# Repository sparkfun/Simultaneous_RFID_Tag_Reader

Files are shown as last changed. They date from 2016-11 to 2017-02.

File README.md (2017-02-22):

SparkFun Simultaneous RFID Tag Reader Breakout
=============================================

SparkFun Simultaneous RFID Tag Reader

[* SparkFun Simultaneous RFID Tag Reader Breakout](https://www.sparkfun.com/products/14066)

A breakout board the for UHF RFID module (M6E-NANO) from ThingMagic. 
Capable of reading multiple 860-920MHz UHF RFID tags at the same time with increased read distance. 
You can also write to tags to boot. 

Board works either as shield or as stand alone device (using a USB to Serial converter).

Repository Contents
-------------------

* **/Documentation** - Data sheets, additional product information
* **/Hardware** - Eagle design files (.brd, .sch)
* **/Libraries** - Libraries for use with the Simultaneous RFID Tag Reader
* **/Production** - Production panel files (.brd)

Documentation
--------------
* **[Library](https://github.com/sparkfun/SparkFun_Simultaneous_RFID_Tag_Reader_Library)** - Arduino library for the Tag Reader.
* **[Hookup Guide](https://learn.sparkfun.com/tutorials/simultaneous-rfid-tag-reader-hookup-guide)** - Basic hookup guide for the Tag Reader.
* **[SparkFun Fritzing repo](https://github.com/sparkfun/Fritzing_Parts)** - Fritzing diagrams for SparkFun products.
* **[SparkFun 3D Model repo](https://github.com/sparkfun/3D_Models)** - 3D models of SparkFun products. 

License Information
-------------------

This product is _**open source**_! 

Please review the LICENSE.md file for license information. 

If you have any questions or concerns on licensing, please contact techsupport@sparkfun.com.

Distributed as-is; no warranty is given.

- Your friends at SparkFun.

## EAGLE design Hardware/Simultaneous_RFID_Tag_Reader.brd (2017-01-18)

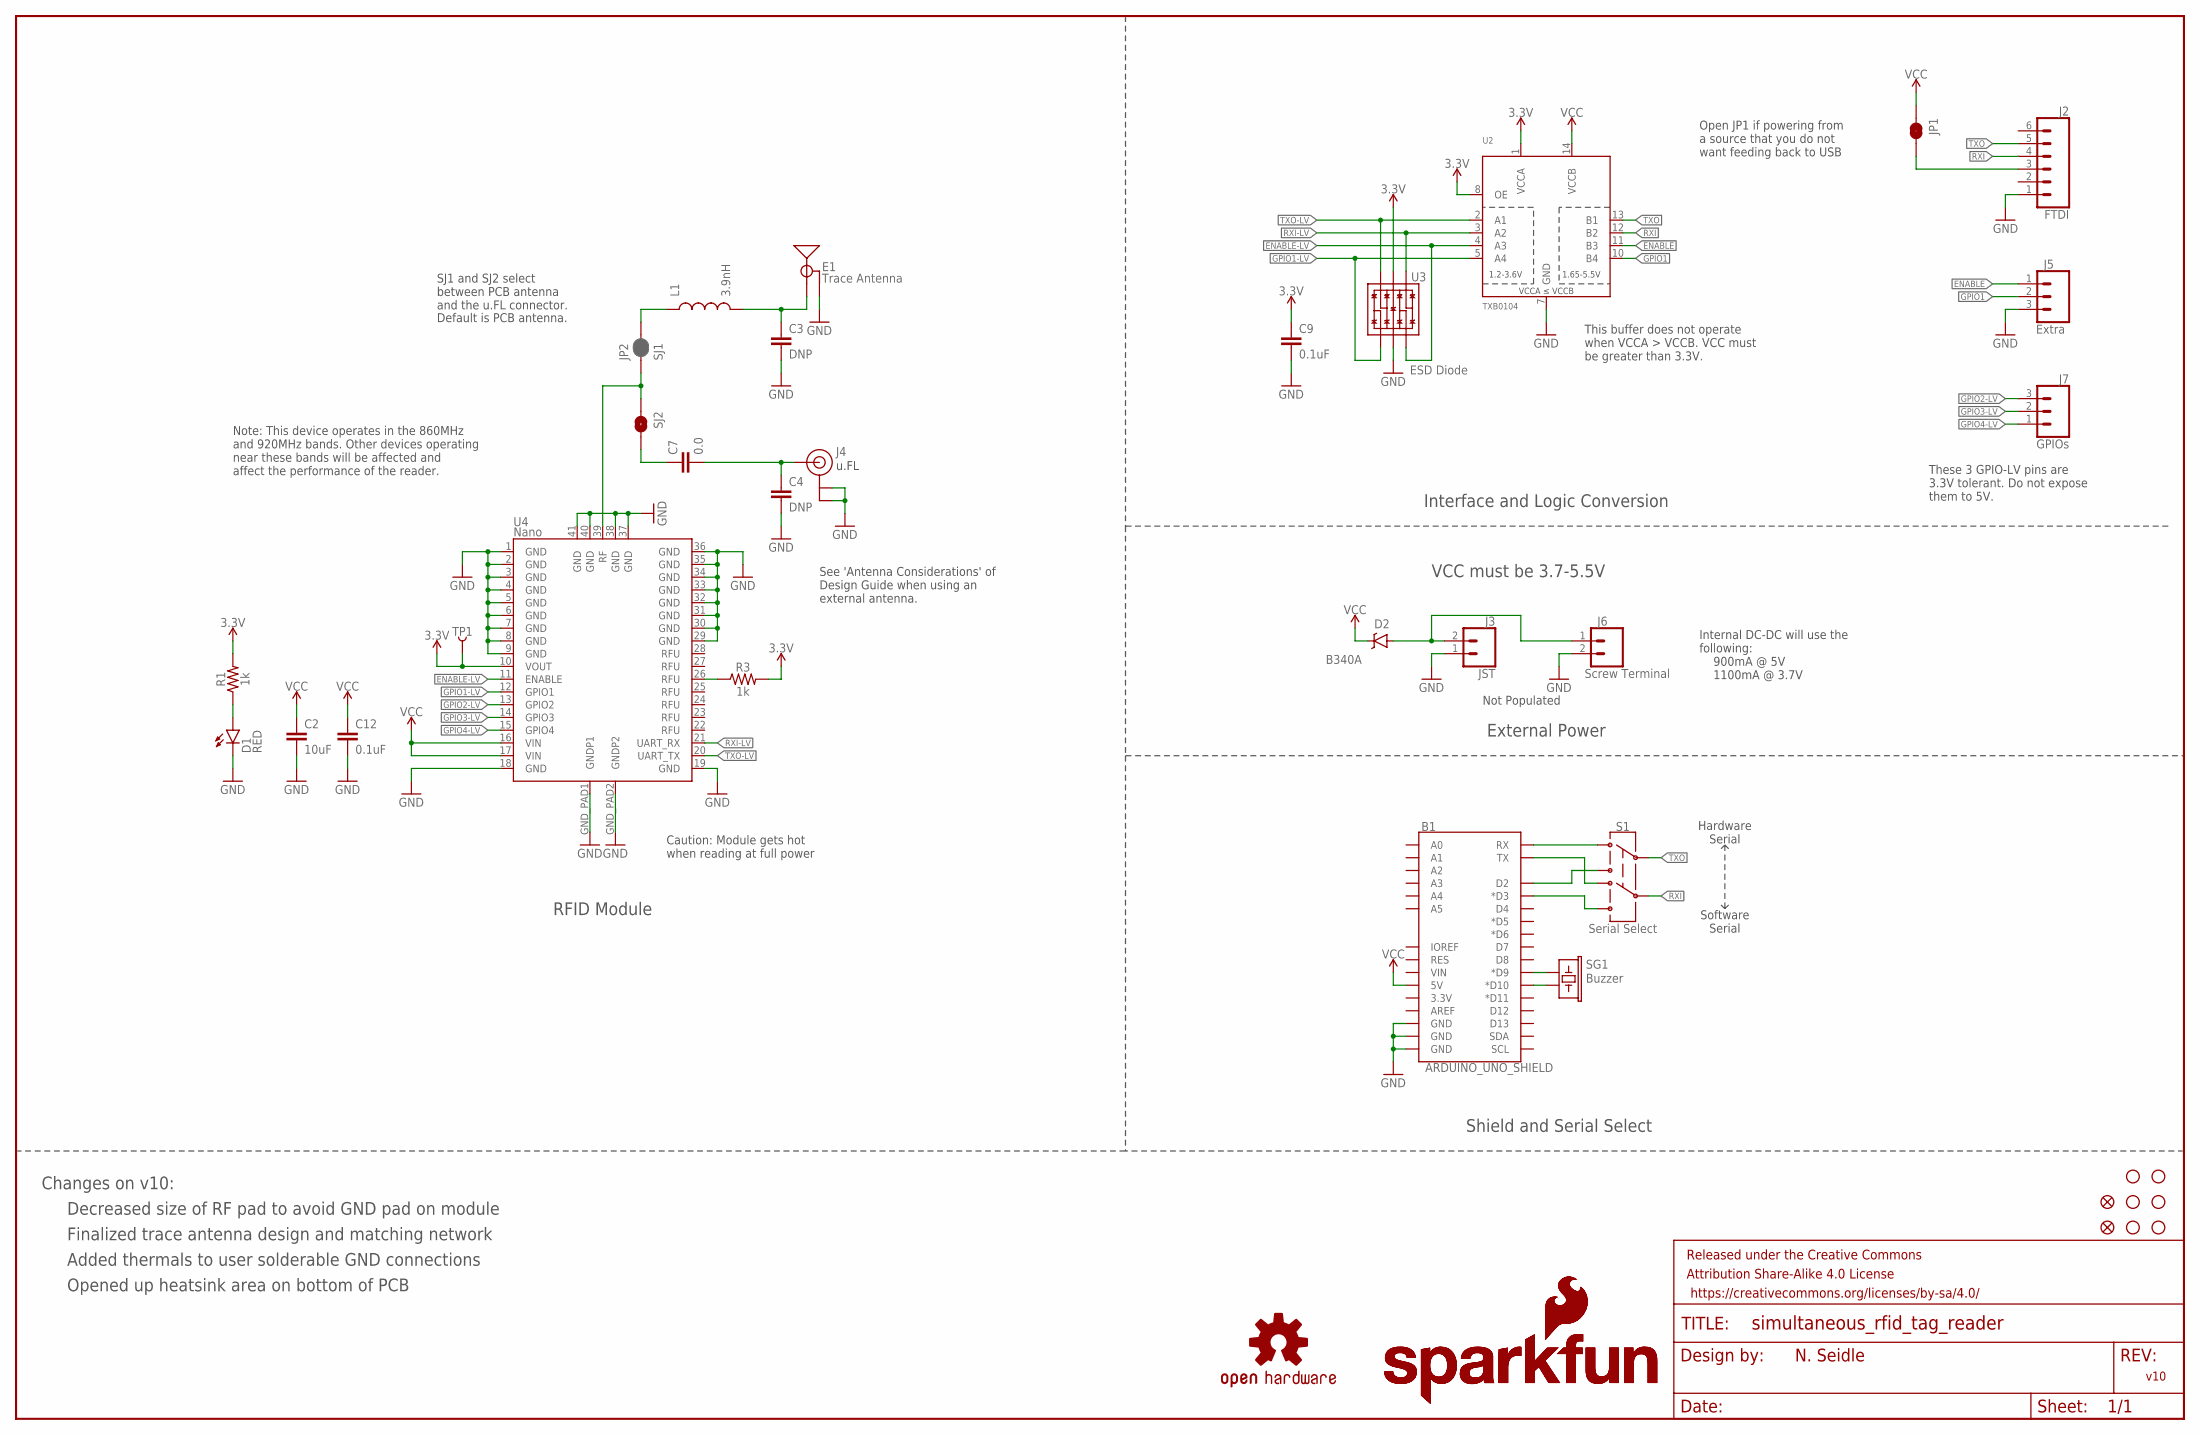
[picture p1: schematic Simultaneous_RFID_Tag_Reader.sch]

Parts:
B1: ARDUINO_UNO_SHIELD; UNO_R3_SHIELD
C2: 10uF; 0805
C3, C4: DNP; 0603
C7: 0.0; 0603
C9, C12: 0.1uF; 0603
D1: RED; LED-0603
D2: B340A; SMA-DIODE
E1: Trace Antenna; 915MHZ_ANTENNA_TRIMBLE
FID1, FID2: FIDUCIAL1X2; FIDUCIAL-1X2
FRAME1: FRAME-LEDGER; CREATIVE_COMMONS
J2: FTDI; 1X06
J3: JST; JST-2-PTH
J4: U.FL
J5: Extra; 1X03
J6: Screw Terminal; SCREWTERMINAL-3.5MM-2
J7: GPIOs; 1X03
JP1: JUMPER-SMT_2_NC_TRACE_SILK; SMT-JUMPER_2_NC_TRACE_SILK
JP2: SJ1; SMT-JUMPER_2_NO_NO-SILK
L1: 3.9nH; 0603
LOGO1, LOGO3: SFE_LOGO_NAME_FLAME.1_INCH; SFE_LOGO_NAME_FLAME_.1
LOGO2: OSHW-LOGOS; OSHW-LOGO-S
R1, R3: 1k; 0603
S1: Serial Select; SWITCH_DPDT_SMD_AYZ0202
SG1: Buzzer; BUZZER-CCV
SJ2: JUMPER-SMT_2_NO_NO-SILK; SMT-JUMPER_2_NO_NO-SILK
STANDOFF1, STANDOFF2, STANDOFF3, STANDOFF4, STANDOFF7, STANDOFF8: STAND-OFF
TP1: TEST-POINT3; PAD.03X.03
U2: TXB0104; SO14
U3: ESD Diode; SOT-23-6
U4: Nano; NANO_MODULE

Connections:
3.3V: C9.1, R1.2, R3.2, TP1.P$1, U2.1 (VCCA), U2.8 (OE), U3.5 (VCC), U4.10 (VOUT)
ANT3: JP2.1, SJ2.1, U4.39 (RF)
ENABLE: J5.1, U2.11 (B3)
ENABLE-LV: U2.4 (A3), U3.3 (IO2), U4.11 (ENABLE)
GND: B1.GND@0 (GND), B1.GND@1 (GND), B1.GND@2 (GND), C2.2, C3.2, C4.2, C9.2, C12.2, D1.C, E1.GND@1 (GND), E1.GND@2 (GND), E1.GND@3 (GND), J2.1, J3.1, J4.P$1 (GND), J4.P$2 (GND), J5.3, J6.2, U2.7 (GND), U3.2 (VSS), U4.1 (GND), U4.2 (GND), U4.3 (GND), U4.4 (GND), U4.5 (GND), U4.6 (GND), U4.7 (GND), U4.8 (GND), U4.9 (GND), U4.18 (GND), U4.19 (GND), U4.29 (GND), U4.30 (GND), U4.31 (GND), U4.32 (GND), U4.33 (GND), U4.34 (GND), U4.35 (GND), U4.36 (GND), U4.37 (GND), U4.38 (GND), U4.40 (GND), U4.41 (GND), U4.GND_PAD1 (GNDP1), U4.GND_PAD2 (GNDP2)
GPIO1: J5.2, U2.10 (B4)
GPIO1-LV: U2.5 (A4), U3.1 (IO1), U4.12 (GPIO1)
GPIO2-LV: J7.3, U4.13 (GPIO2)
GPIO3-LV: J7.2, U4.14 (GPIO3)
GPIO4-LV: J7.1, U4.15 (GPIO4)
unnamed: C3.1, E1.ANT (SIGNAL), L1.2
unnamed: JP2.2, L1.1
unnamed: C7.1, SJ2.2
unnamed: R3.1, U4.26 (RFU)
unnamed: C4.1, C7.2, J4.P$3 (SIGNAL)
unnamed: D1.A, R1.1
unnamed: J2.3, JP1.2
unnamed: B1.RX, S1.1
unnamed: B1.TX, S1.4
unnamed: B1.D9 (*D9), SG1.+ (1)
unnamed: D2.A, J3.2, J6.1
unnamed: B1.D10 (*D10), SG1.- (2)
RXI: J2.4, S1.5, U2.12 (B2)
RXI-LV: U2.3 (A2), U3.4 (IO3), U4.21 (UART_RX)
SOFT-RX: B1.D2, S1.3
SOFT-TX: B1.D3 (*D3), S1.6
TXO: J2.5, S1.2, U2.13 (B1)
TXO-LV: U2.2 (A1), U3.6 (IO4), U4.20 (UART_TX)
VCC: B1.5V, C2.1, C12.1, D2.C, JP1.1, U2.14 (VCCB), U4.16 (VIN), U4.17 (VIN)

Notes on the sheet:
v10
N. Seidle
Interface and Logic Conversion
VCC must be 3.7-5.5V
Internal DC-DC will use the following: 900mA @ 5V 1100mA @ 3.7V
RFID Module
SJ1 and SJ2 select between PCB antenna and the u.FL connector.
Note: This device operates in the 860MHz and 920MHz bands. Other devices operating near these bands will be affected and affect the performance of the reader.
See 'Antenna Considerations' of Design Guide when using an external antenna.
u.FL
Hardware Serial
Software Serial
External Power
Shield and Serial Select
Default is PCB antenna.
Not Populated
Open JP1 if powering from a source that you do not want feeding back to USB
These 3 GPIO-LV pins are 3.3V tolerant. Do not expose them to 5V.
Decreased size of RF pad to avoid GND pad on module
Finalized trace antenna design and matching network
Changes on v10:
Added thermals to user solderable GND connections
Caution: Module gets hot when reading at full power
Opened up heatsink area on bottom of PCB
This buffer does not operate when VCCA > VCCB. VCC must be greater than 3.3V.

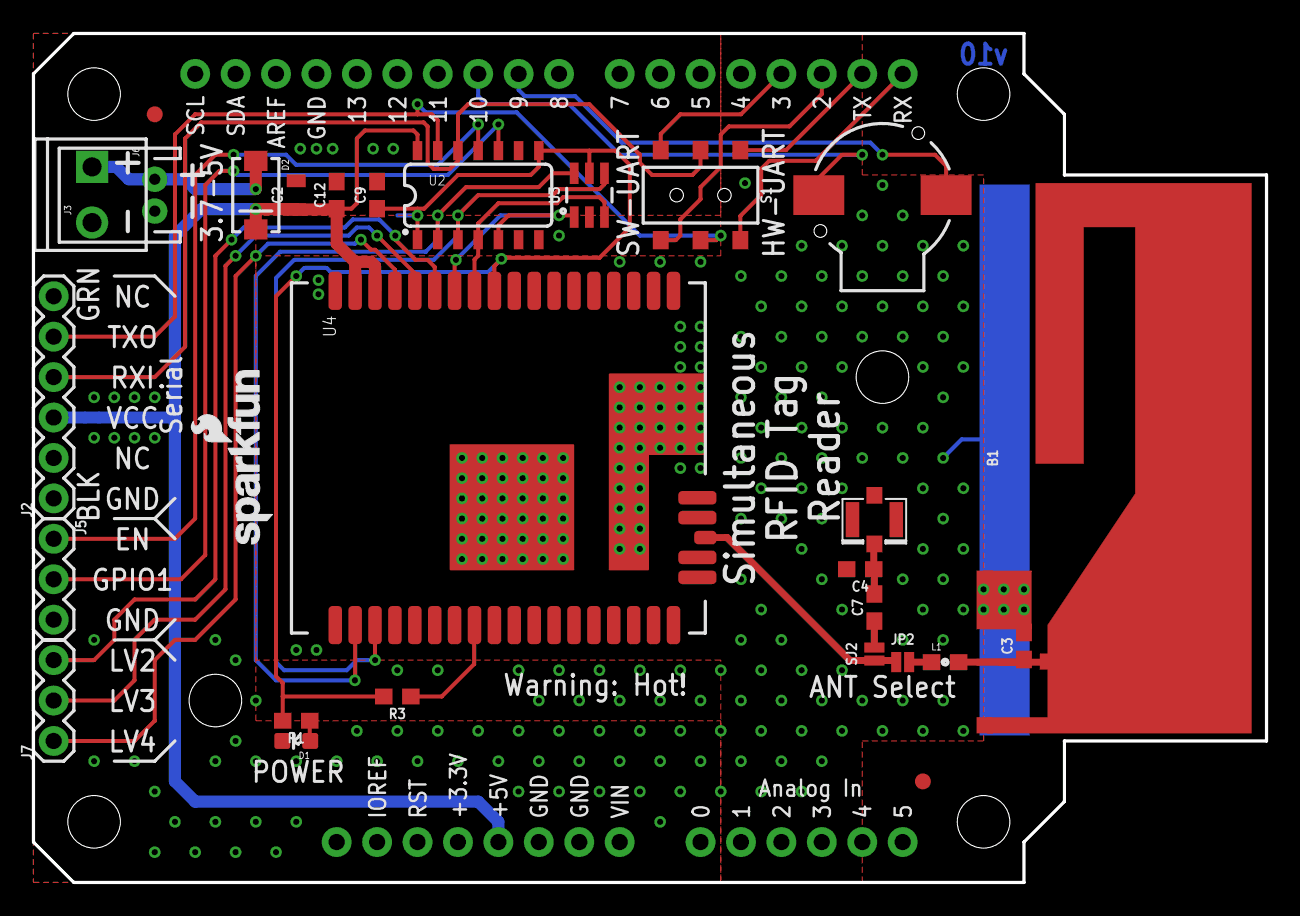
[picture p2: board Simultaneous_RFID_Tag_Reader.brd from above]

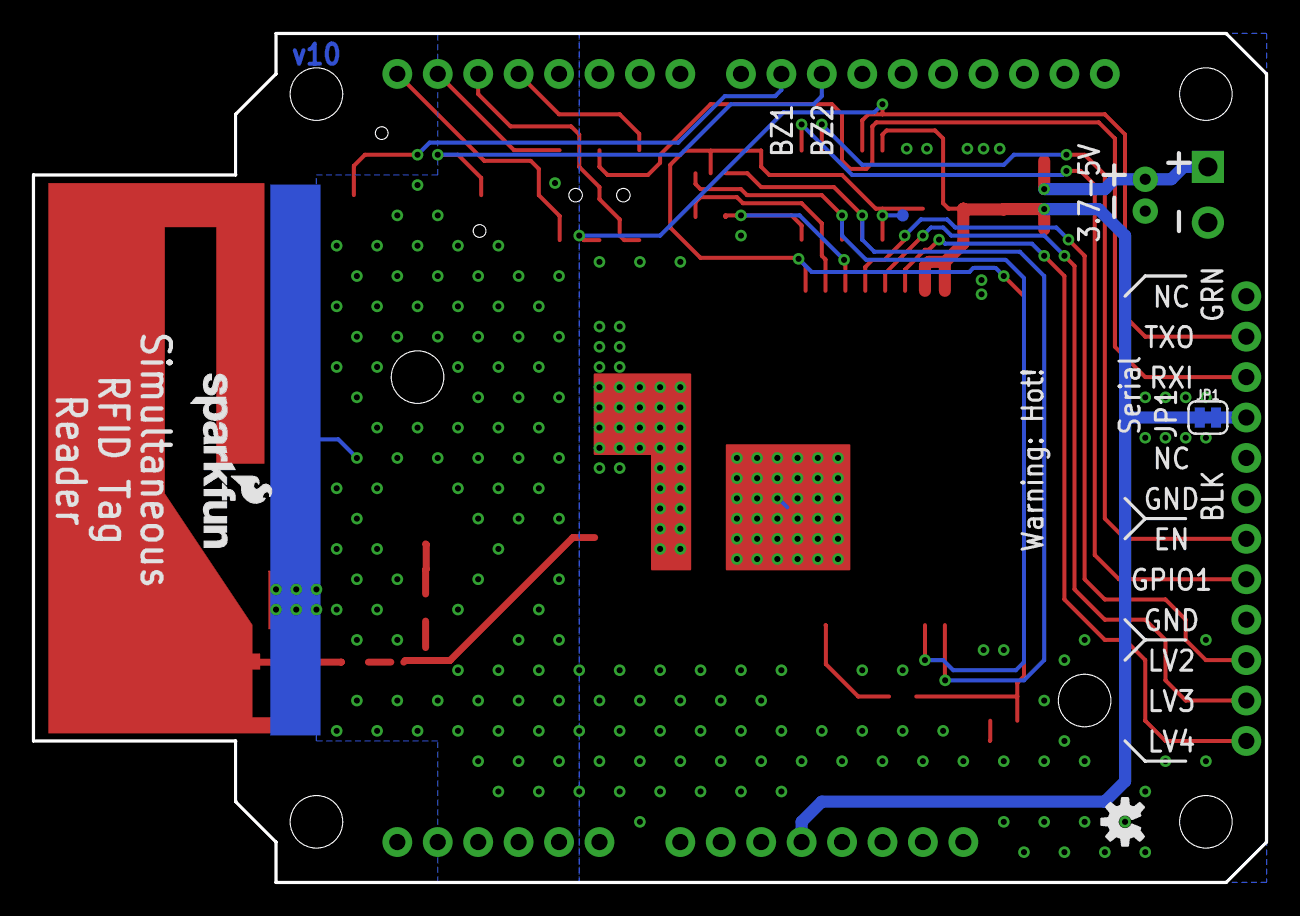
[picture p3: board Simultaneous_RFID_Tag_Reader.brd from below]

Board: 2 copper layers, 77.5 x 53.3 mm, 40 parts (4 on the bottom side), 29 nets.

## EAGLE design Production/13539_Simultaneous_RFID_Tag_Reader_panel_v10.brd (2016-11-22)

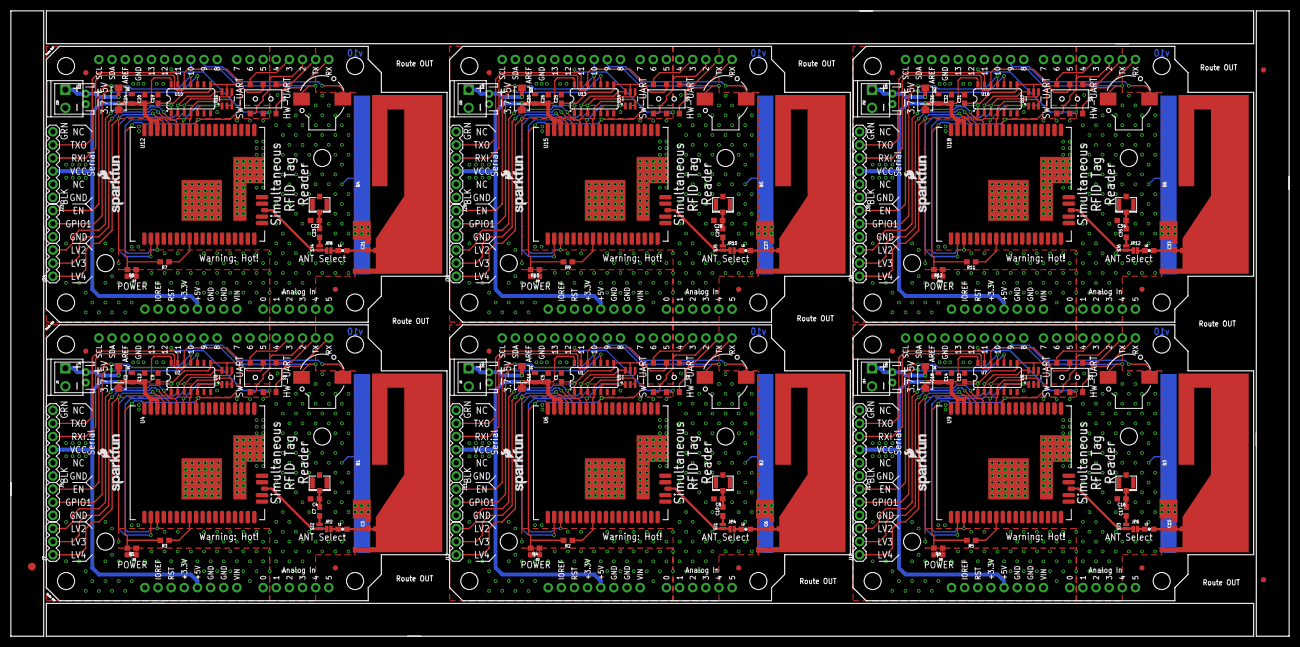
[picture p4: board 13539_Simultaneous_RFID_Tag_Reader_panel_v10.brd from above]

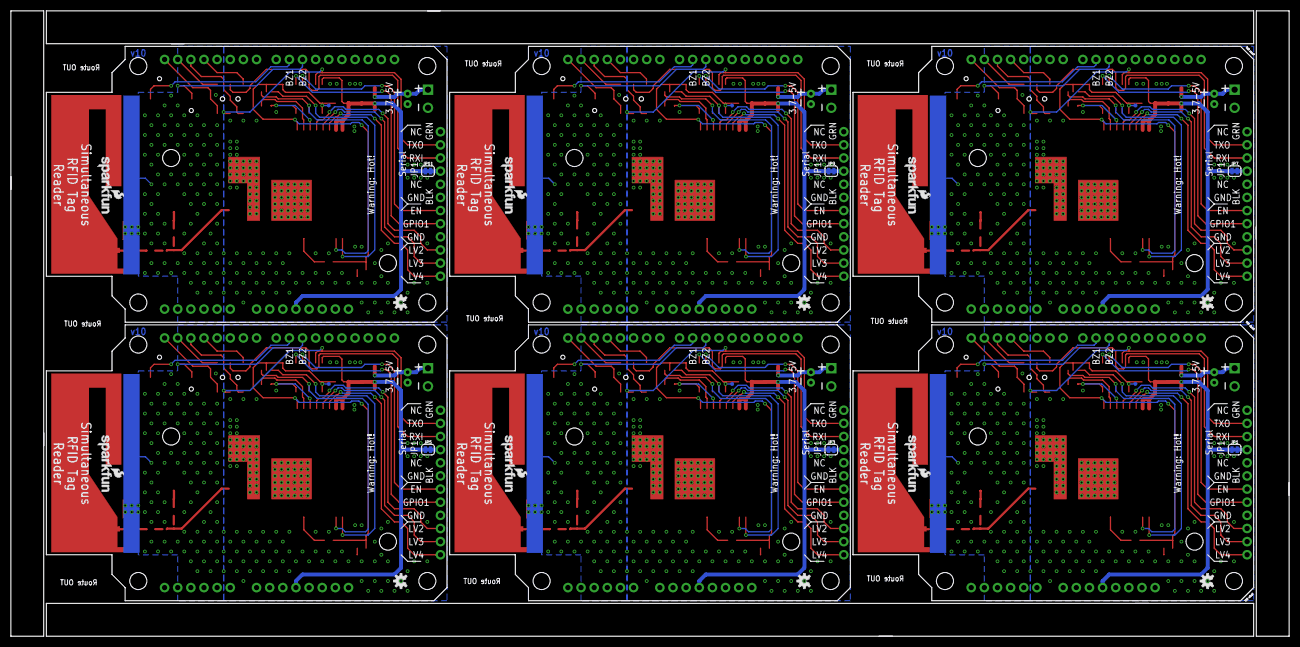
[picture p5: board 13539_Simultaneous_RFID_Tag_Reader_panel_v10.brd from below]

Board: 2 copper layers, 247.1 x 120.9 mm, 237 parts (24 on the bottom side), 174 nets.

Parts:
B1, B2, B3, B4, B5, B6: ARDUINO_UNO_SHIELD; UNO_R3_SHIELD
C1, C5, C9, C12, C13, C14, C19, C20, C25, C26, C31, C32: 0.1uF; 0603
C2, C11, C18, C24, C30, C36: 10uF; 0805
C3, C6, C15, C21, C27, C33: DNP; 0603
C4, C7, C8, C10, C16, C17, C22, C23, C28, C29, C34, C35: TBD; 0603
D1, D3, D5, D7, D9, D11: RED; LED-0603
D2, D4, D6, D8, D10, D12: B340A; SMA-DIODE
E1, E2, E3, E4, E5, E6: Trace Antenna; 915MHZ_ANTENNA_TRIMBLE
E$1: FIDUCIAL-1.5X3
E$7, E$8: FIDUCIAL-1X2
FID1, FID2, FID3, FID4, FID5, FID6, FID7, FID8, FID9, FID10, FID11, FID12: FIDUCIAL1X2; FIDUCIAL-1X2
J1, J2, J13, J19, J25, J31: FTDI; 1X06
J3, J8, J14, J20, J26, J32: JST; JST-2-PTH
J4, J9, J15, J21, J27, J33: U.FL
J5, J11, J17, J23, J29, J35: Extra; 1X03
J6, J10, J16, J22, J28, J34: Screw Terminal; SCREWTERMINAL-3.5MM-2
J7, J12, J18, J24, J30, J36: GPIOs; 1X03
JP1, JP3, JP5, JP7, JP9, JP11: SMT-JUMPER_2_NC_TRACE_SILK
JP2, JP4, JP6, JP8, JP10, JP12: SJ1; SMT-JUMPER_2_NO_NO-SILK
L1, L2, L3, L4, L5, L6: 3.9nH; 0603
LOGO1, LOGO3, LOGO4, LOGO6, LOGO7, LOGO9, LOGO10, LOGO12, LOGO13, LOGO15, LOGO16, LOGO18: SFE_LOGO_NAME_FLAME.1_INCH; SFE_LOGO_NAME_FLAME_.1
LOGO2, LOGO5, LOGO8, LOGO11, LOGO14, LOGO17: OSHW-LOGOS; OSHW-LOGO-S
R1, R2, R3, R4, R5, R6, R7, R8, R9, R10, R11, R12: 1k; 0603
S1, S2, S3, S4, S5, S6: Serial Select; SWITCH_DPDT_SMD_AYZ0202
SG1, SG2, SG3, SG4, SG5, SG6: Buzzer; BUZZER-CCV
SJ1, SJ2, SJ3, SJ4, SJ5, SJ6: SMT-JUMPER_2_NO_NO-SILK
STANDOFF1, STANDOFF2, STANDOFF3, STANDOFF4, STANDOFF5, STANDOFF6, STANDOFF7, STANDOFF8, STANDOFF9, STANDOFF10, STANDOFF11, STANDOFF12, STANDOFF13, STANDOFF14, STANDOFF15, STANDOFF16, STANDOFF17, STANDOFF18, STANDOFF19, STANDOFF20, STANDOFF21, STANDOFF22, STANDOFF23, STANDOFF24, STANDOFF25, STANDOFF26, STANDOFF27, STANDOFF28, STANDOFF29, STANDOFF30, STANDOFF31, STANDOFF32, STANDOFF33, STANDOFF34, STANDOFF35, STANDOFF36: STAND-OFF
TP1, TP2, TP3, TP4, TP5, TP6: PAD.03X.03
U1, U2, U7, U10, U13, U16: TXB0104; SO14
U3, U5, U8, U11, U14, U17: ESD Diode; SOT-23-6
U4, U6, U9, U12, U15, U18: Nano; NANO_MODULE

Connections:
3.3V: C9.1, R1.2, R3.2, TP1.P$1, U2.1, U2.8, U3.5, U4.10
3.3V1: C1.1, R2.2, R4.2, TP2.P$1, U1.1, U1.8, U5.5, U6.10
3.3V2: C13.1, R5.2, R6.2, TP3.P$1, U7.1, U7.8, U8.5, U9.10
3.3V3: C19.1, R7.2, R8.2, TP4.P$1, U10.1, U10.8, U11.5, U12.10
3.3V4: C25.1, R9.2, R10.2, TP5.P$1, U13.1, U13.8, U14.5, U15.10
3.3V5: C31.1, R11.2, R12.2, TP6.P$1, U16.1, U16.8, U17.5, U18.10
ANT1: JP4.1, SJ1.1, U6.39
ANT2: JP6.1, SJ3.1, U9.39
ANT3: JP2.1, SJ2.1, U4.39
ANT4: JP8.1, SJ4.1, U12.39
ANT5: JP10.1, SJ5.1, U15.39
ANT6: JP12.1, SJ6.1, U18.39
ENABLE: J5.1, U2.11
ENABLE1: J11.1, U1.11
ENABLE2: J17.1, U7.11
ENABLE3: J23.1, U10.11
ENABLE4: J29.1, U13.11
ENABLE5: J35.1, U16.11
ENABLE-LV: U2.4, U3.3, U4.11
ENABLE-LV1: U1.4, U5.3, U6.11
ENABLE-LV2: U7.4, U8.3, U9.11
ENABLE-LV3: U10.4, U11.3, U12.11
ENABLE-LV4: U13.4, U14.3, U15.11
ENABLE-LV5: U16.4, U17.3, U18.11
GND: B1.GND@0, B1.GND@1, B1.GND@2, C2.2, C3.2, C4.2, C9.2, C12.2, D1.C, E1.GND@1, E1.GND@2, E1.GND@3, J2.1, J3.1, J4.P$1, J4.P$2, J5.3, J6.2, U2.7, U3.2, U4.1, U4.2, U4.3, U4.4, U4.5, U4.6, U4.7, U4.8, U4.9, U4.18, U4.19, U4.29, U4.30, U4.31, U4.32, U4.33, U4.34, U4.35, U4.36, U4.37, U4.38, U4.40, U4.41, U4.GND_PAD2
GND1: B2.GND@0, B2.GND@1, B2.GND@2, C1.2, C5.2, C6.2, C8.2, C11.2, D3.C, E2.GND@1, E2.GND@2, E2.GND@3, J1.1, J8.1, J9.P$1, J9.P$2, J10.2, J11.3, U1.7, U5.2, U6.1, U6.2, U6.3, U6.4, U6.5, U6.6, U6.7, U6.8, U6.9, U6.18, U6.19, U6.29, U6.30, U6.31, U6.32, U6.33, U6.34, U6.35, U6.36, U6.37, U6.38, U6.40, U6.41, U6.GND_PAD2
GND2: B3.GND@0, B3.GND@1, B3.GND@2, C13.2, C14.2, C15.2, C16.2, C18.2, D5.C, E3.GND@1, E3.GND@2, E3.GND@3, J13.1, J14.1, J15.P$1, J15.P$2, J16.2, J17.3, U7.7, U8.2, U9.1, U9.2, U9.3, U9.4, U9.5, U9.6, U9.7, U9.8, U9.9, U9.18, U9.19, U9.29, U9.30, U9.31, U9.32, U9.33, U9.34, U9.35, U9.36, U9.37, U9.38, U9.40, U9.41, U9.GND_PAD2
GND3: B4.GND@0, B4.GND@1, B4.GND@2, C19.2, C20.2, C21.2, C22.2, C24.2, D7.C, E4.GND@1, E4.GND@2, E4.GND@3, J19.1, J20.1, J21.P$1, J21.P$2, J22.2, J23.3, U10.7, U11.2, U12.1, U12.2, U12.3, U12.4, U12.5, U12.6, U12.7, U12.8, U12.9, U12.18, U12.19, U12.29, U12.30, U12.31, U12.32, U12.33, U12.34, U12.35, U12.36, U12.37, U12.38, U12.40, U12.41, U12.GND_PAD2
GND4: B5.GND@0, B5.GND@1, B5.GND@2, C25.2, C26.2, C27.2, C28.2, C30.2, D9.C, E5.GND@1, E5.GND@2, E5.GND@3, J25.1, J26.1, J27.P$1, J27.P$2, J28.2, J29.3, U13.7, U14.2, U15.1, U15.2, U15.3, U15.4, U15.5, U15.6, U15.7, U15.8, U15.9, U15.18, U15.19, U15.29, U15.30, U15.31, U15.32, U15.33, U15.34, U15.35, U15.36, U15.37, U15.38, U15.40, U15.41, U15.GND_PAD2
GND5: B6.GND@0, B6.GND@1, B6.GND@2, C31.2, C32.2, C33.2, C34.2, C36.2, D11.C, E6.GND@1, E6.GND@2, E6.GND@3, J31.1, J32.1, J33.P$1, J33.P$2, J34.2, J35.3, U16.7, U17.2, U18.1, U18.2, U18.3, U18.4, U18.5, U18.6, U18.7, U18.8, U18.9, U18.18, U18.19, U18.29, U18.30, U18.31, U18.32, U18.33, U18.34, U18.35, U18.36, U18.37, U18.38, U18.40, U18.41, U18.GND_PAD2
GPIO1: J5.2, U2.10
GPIO1-LV: U2.5, U3.1, U4.12
GPIO1-LV1: U1.5, U5.1, U6.12
GPIO1-LV2: U7.5, U8.1, U9.12
GPIO1-LV3: U10.5, U11.1, U12.12
GPIO1-LV4: U13.5, U14.1, U15.12
GPIO1-LV5: U16.5, U17.1, U18.12
GPIO2: J11.2, U1.10
GPIO2-LV: J7.3, U4.13
GPIO2-LV1: J12.3, U6.13
GPIO2-LV2: J18.3, U9.13
GPIO2-LV3: J24.3, U12.13
GPIO2-LV4: J30.3, U15.13
GPIO2-LV5: J36.3, U18.13
GPIO3: J17.2, U7.10
GPIO3-LV: J7.2, U4.14
GPIO3-LV1: J12.2, U6.14
GPIO3-LV2: J18.2, U9.14
GPIO3-LV3: J24.2, U12.14
GPIO3-LV4: J30.2, U15.14
GPIO3-LV5: J36.2, U18.14
GPIO4: J23.2, U10.10
GPIO4-LV: J7.1, U4.15
GPIO4-LV1: J12.1, U6.15
GPIO4-LV2: J18.1, U9.15
GPIO4-LV3: J24.1, U12.15
GPIO4-LV4: J30.1, U15.15
GPIO4-LV5: J36.1, U18.15
GPIO5: J29.2, U13.10
GPIO6: J35.2, U16.10
unnamed: C3.1, E1.ANT, L1.2
unnamed: JP2.2, L1.1
unnamed: C7.1, SJ2.2
unnamed: R3.1, U4.26
unnamed: C4.1, C7.2, J4.P$3
unnamed: D1.A, R1.1
unnamed: J2.3, JP1.2
unnamed: B1.RX, S1.1
unnamed: B1.TX, S1.4
unnamed: B1.D9, SG1.+
unnamed: D2.A, J3.2, J6.1
unnamed: B1.D10, SG1.-
unnamed: R2.1, U6.26
unnamed: B2.RX, S2.1
unnamed: B2.TX, S2.4
unnamed: C6.1, E2.ANT, L2.2
unnamed: JP4.2, L2.1
unnamed: C10.1, SJ1.2
unnamed: C8.1, C10.2, J9.P$3
unnamed: D3.A, R4.1
unnamed: J1.3, JP3.2
unnamed: D4.A, J8.2, J10.1
unnamed: B2.D9, SG2.+
unnamed: B2.D10, SG2.-
unnamed: R5.1, U9.26
unnamed: B3.RX, S3.1
unnamed: B3.TX, S3.4
unnamed: C15.1, E3.ANT, L3.2
unnamed: JP6.2, L3.1
unnamed: C17.1, SJ3.2
unnamed: C16.1, C17.2, J15.P$3
unnamed: D5.A, R6.1
unnamed: J13.3, JP5.2
unnamed: D6.A, J14.2, J16.1
unnamed: B3.D9, SG3.+
unnamed: B3.D10, SG3.-
unnamed: R7.1, U12.26
unnamed: B4.RX, S4.1
unnamed: B4.TX, S4.4
unnamed: C21.1, E4.ANT, L4.2
unnamed: JP8.2, L4.1
unnamed: C23.1, SJ4.2
unnamed: C22.1, C23.2, J21.P$3
unnamed: D7.A, R8.1
unnamed: J19.3, JP7.2
unnamed: D8.A, J20.2, J22.1
unnamed: B4.D9, SG4.+
unnamed: B4.D10, SG4.-
unnamed: R9.1, U15.26
unnamed: B5.RX, S5.1
unnamed: B5.TX, S5.4
unnamed: C27.1, E5.ANT, L5.2
unnamed: JP10.2, L5.1
unnamed: C29.1, SJ5.2
unnamed: C28.1, C29.2, J27.P$3
unnamed: D9.A, R10.1
unnamed: J25.3, JP9.2
unnamed: D10.A, J26.2, J28.1
unnamed: B5.D9, SG5.+
unnamed: B5.D10, SG5.-
unnamed: R11.1, U18.26
unnamed: B6.RX, S6.1
unnamed: B6.TX, S6.4
unnamed: C33.1, E6.ANT, L6.2
unnamed: JP12.2, L6.1
unnamed: C35.1, SJ6.2
unnamed: C34.1, C35.2, J33.P$3
unnamed: D11.A, R12.1
unnamed: J31.3, JP11.2
unnamed: D12.A, J32.2, J34.1
unnamed: B6.D9, SG6.+
unnamed: B6.D10, SG6.-
RXI: J2.4, S1.5, U2.12
RXI1: J1.4, S2.5, U1.12
RXI2: J13.4, S3.5, U7.12
RXI3: J19.4, S4.5, U10.12
RXI4: J25.4, S5.5, U13.12
RXI5: J31.4, S6.5, U16.12
RXI-LV: U2.3, U3.4, U4.21
RXI-LV1: U1.3, U5.4, U6.21
RXI-LV2: U7.3, U8.4, U9.21
RXI-LV3: U10.3, U11.4, U12.21
RXI-LV4: U13.3, U14.4, U15.21
RXI-LV5: U16.3, U17.4, U18.21
SOFT-RX: B1.D2, S1.3
SOFT-RX1: B2.D2, S2.3
SOFT-RX2: B3.D2, S3.3
SOFT-RX3: B4.D2, S4.3
SOFT-RX4: B5.D2, S5.3
SOFT-RX5: B6.D2, S6.3
SOFT-TX: B1.D3, S1.6
SOFT-TX1: B2.D3, S2.6
SOFT-TX2: B3.D3, S3.6
SOFT-TX3: B4.D3, S4.6
SOFT-TX4: B5.D3, S5.6
SOFT-TX5: B6.D3, S6.6
TXO: J2.5, S1.2, U2.13
TXO1: J1.5, S2.2, U1.13
TXO2: J13.5, S3.2, U7.13
TXO3: J19.5, S4.2, U10.13
TXO4: J25.5, S5.2, U13.13
TXO5: J31.5, S6.2, U16.13
TXO-LV: U2.2, U3.6, U4.20
TXO-LV1: U1.2, U5.6, U6.20
TXO-LV2: U7.2, U8.6, U9.20
TXO-LV3: U10.2, U11.6, U12.20
TXO-LV4: U13.2, U14.6, U15.20
TXO-LV5: U16.2, U17.6, U18.20
VCC: B1.5V, C2.1, C12.1, D2.C, JP1.1, U2.14, U4.16, U4.17
VCC1: B2.5V, C5.1, C11.1, D4.C, JP3.1, U1.14, U6.16, U6.17
VCC2: B3.5V, C14.1, C18.1, D6.C, JP5.1, U7.14, U9.16, U9.17
VCC3: B4.5V, C20.1, C24.1, D8.C, JP7.1, U10.14, U12.16, U12.17
VCC4: B5.5V, C26.1, C30.1, D10.C, JP9.1, U13.14, U15.16, U15.17
VCC5: B6.5V, C32.1, C36.1, D12.C, JP11.1, U16.14, U18.16, U18.17

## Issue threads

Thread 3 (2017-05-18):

ERROR_COMMAND_RESPONSE_TIMEOUT

robertshearing, 2017-05-18:
Hi,
I'm trying to get this code working but I cannot get the board to start.
I've found that when the call to getVersion:
`nano.getVersion();`
is called I get a 1 returned (ERROR_COMMAND_RESPONSE_TIMEOUT)

I have the board working using the thing magic Universal reader Assistant and I'm powering the Arduino (Leonardo) with an external 5v power source. I have checked that all the required pins (gnd, 5v, D2, D3, D9, D10) are all good connections and it is switched to SW_UART. The power light is on and I can get the buzzer to sound.

Are you aware of this problem happening and is there a way I can diagnose it further or fix it?

Thanks,
Rob

nseidle, 2017-05-18:
Hi Rob,

My initial guess is that the serial from the Leonardo is not getting past the conversion circuitry. The TXB0104 in [the schematic](https://cdn.sparkfun.com/datasheets/Sensors/ID/Simultaneous_RFID_Tag_Reader.pdf) requires that VCC going into the board be larger than 3.3V.  But the Leonardo should be providing 5V to the board so I don't think that's the culprit...

Does Leonardo handle software serial correctly? Ok, looks like only a [handful of pins](https://www.arduino.cc/en/Reference/SoftwareSerial) can be used on Leonardo for software serial, but 9 and 10 can both be used for RX so that seems to not be the culprit.

Is the Leonardo pulling down the Enable pin on ... nope, not connected.

Do you have a [logic analyzer](https://www.sparkfun.com/products/13195)? It would help verify if serial is getting from Leonardo through TXB0104 to the RFID module. Ah, or here's an idea: you have a USB-to-Serial adapter so if you connect only GND and the RXI pin on the 6-pin serial connection to your USB-to-Serial adapter you should be able to inspect via a terminal what the Leonardo is sending to the module.

Sorry I don't have a smoking gun for you yet. Please let me know what you find.

robertshearing, 2017-05-19:
Hi Nate,

Thanks for getting back to me on this one so quickly.
It turns out that Leonardo (and Mega) can't use pins 2 and 3 for the Software Serial library: https://www.arduino.cc/en/Reference/softwareSerial

So I just wired it up differently to use pins 9 and 10 for the Rx Tx and it worked immediately!
I have now just switched over the buzzer pins and the SW-UART pins with jumper wires.

It might be good to add this in somewhere in the user guide incase other people have the same issue.

Thanks again for helping out,
Rob

nseidle, 2017-05-19:
Why did I think the Software TX/RX were on pins 9/10? Excellent! Glad you got it working.

FYI - The software serial limitation only applies to RX pins (because the library needs a change interrupt). You should only need to move D2 to something else (TX from RFID into RX on pin 2 on Leonardo).

nseidle, 2017-05-19:
Notes added on [hardware page](https://learn.sparkfun.com/tutorials/simultaneous-rfid-tag-reader-hookup-guide/hardware-hookup) and [example 1](https://learn.sparkfun.com/tutorials/simultaneous-rfid-tag-reader-hookup-guide/example-1---constant-read).

Closed 2017-05-19.

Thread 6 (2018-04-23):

Add jumper to JP1 external power jumper

nseidle, 2018-04-23:
To make it easier to swap back and forth

alwaysAn0n, 2019-07-31:
This would be very useful.  I can't imagine why it doesn't ship with one.

ReneElizondo, 2021-12-29:
Yes please, that would be incredible useful, but please don't stop there, you  should also add jumpers to the antenna select so that its easy to switch between the external and internal antenna.

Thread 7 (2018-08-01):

Send a standard Class−1 Generation−2 UHF Select command

Holy1990, 2018-08-01:
I need to read the temperature from my RFID temperature sensor. For reading the temperature, 2 step process requiring standard UHF Select and Read commands.

1. Send a **standard Class−1 Generation−2 UHF Select command** with the parameters described in Table 6 to initialize the temperature sensor and calculate a Temperature Code. The Select command to be followed by 2 ms of continuous wave before the reader issues any further commands. This pause
gives the temperature sensor circuit time to run. The reader must not power down at any time between the Select and Read commands.

2. Send a standard Class−1 Generation−2 UHF Read command to retrieve the Temperature Code from the sensor tag memory at the location given in Table 7.

 Is this SparkFun Simultaneous RFID Tag Reader Library  for Arduino support to send the **Select command**? i only able to send the read command follow the example provided by sparkfun on Arduino.

nseidle, 2018-08-01:
Thanks for posting! And you did get the issue posted [on the lib repo](https://github.com/sparkfun/SparkFun_Simultaneous_RFID_Tag_Reader_Library/issues/12) where it is best. I'm closing this one because it's a duplicate.

Closed 2018-08-01.

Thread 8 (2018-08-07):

Not being able to read data from HID Iron Tag 206 (8Kb usr mem)

edsonms, 2018-08-07:
Hi,

I have been trying to read the user memory of the tag Iron Tag 206 using your code but I have no data returned. I was able to read all other tags I have here (quite a few, as HID sent me a box with samples), but for this tag I can't read one single byte. It always returns "Error reading tag data" only for this tag. And inside the userDataRead function, the msg[0] is 1 (ERROR_COMMAND_RESPONSE_TIMEOUT) and once I got it as 2 (ERROR_CORRUPT_RESPONSE).

Have anyone faced similar thing?

nseidle, 2018-08-07:
Have you been able to use the URA to read the tag? If the URA cannot read it then it may be something lower level than what the Arduino library can access.

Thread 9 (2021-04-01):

Read multiple tags at once

adambadge, 2021-04-01:
Hello,

Quick question regarding multiple tag reads.

I have loaded up example sketch 1 and it works great with a single tag and works pretty well. Multiple tags in a sheet of 5 I start to get "Bad CRC" errors Is the Arduino examples sketches designed to provide simultaneous tag scanning capability similar to that of the universal assistant app?

Regards,
Adam

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

nseidle, 2021-04-01:
I suspect it's related to software serial dropping or corrupting characters. Try using a micro with a hardware serial port and let us know if you continue seeing the issue.

Closed 2021-04-01.

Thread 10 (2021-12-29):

Problem connecting to the Nano board using an FTDI Cable 5V.

ReneElizondo, 2021-12-29:
Hello,

I have a **_SparkFun Simultaneous RFID Reader - M6E Nano_** that I interface with a [SparkFun Serial Basic Breakout - CH340G](https://www.sparkfun.com/products/14050) (setup to use 5 volts logic) and everything works perfectly fine. If I leave things exactly the same and I only replace the **_SparkFun Serial Basic Breakout - CH340G_** with a [FTDI Cable 5V](https://www.sparkfun.com/products/9718) things don’t work.

Why is that? Aren’t the **_SparkFun Serial Basic Breakout - CH340G_** and **_FTDI Cable 5V_** supposed to be functionally equivalent?

Note:

*) The **_FTDI Cable 5V_** is recognized by the computer just fine (using the latest drivers) so there are no issues with drivers etc.

*) I have tested the **_FTDI Cable 5V_** cable by communicating with an Arduino board and the cable functions perfectly.

*) The **_FTDI Cable 5V_** cable still fails even if an external / independent 5 VCC power source is provided to the Nano (in this case the only pins used by the **_FTDI Cable 5V_** cable are just RX, TX and ground, the VCC in the cable is disconnected so I don't think the cable is failing due to not being able to provide enough power.

*) The cable fails while trying to do the basic initial handshake (the part where the 'Universal Reader Assistant' software tries to identify the Nano board), I don't even get to the point where I don any RFID reading.

The reason for me using the **_FTDI Cable 5V_**  cable is because I am having all kinds of issues (sporadic ones) connecting to the Nano board via serial. So in order try to diagnose the problem (with my limited skills) I decided to purchase the cable and see if things would work with that cable (just as an experiment). I figured such an experiment may shed some light as to why I am having all the serial connection issues.

I strongly suspect this is not a **_FTDI Cable 5V_** cable issue, my gut feeling tells me this is a Nano issue....

Thanks.

nseidle, 2021-12-30:
Curious. Differences that come to mind: the CH340G has an external crystal where the FT232 uses an internal oscillator. We've seen some rare cases where the CH340C (internal oscillator) is just enough out of spec that it cannot communicate with an ATmega328 (external resonator) for bootloading (115200). Whether it is the CH340C that is off or the external resonator on the ATmega328 - I cannot say. Just know that clocks might be a thing. A [logic analyzer](https://www.sparkfun.com/products/18627) would tell you quickly enough if your serial timing is out of spec.

My last guess is that the FT232 needs to have its CTS pin pulled low. I don't know enough about how the IC is configured in the black blob of the FTDI cable to say if it has a pull down on the CTS pin. If it doesn't, or if it's pulled up, the FT232 won't do transmit until it's low.

ReneElizondo, 2021-12-30:
Thanks Nathan,

A couple of things:

When I connect a logic analyzer (the exact one you mention, I actually purchased that device to troubleshoot exactly this issue) two things happen. When I plug the CH340G board, both the RX and TX lines are completely quiet, they are just high and stay high unless a command is issued the Nano. However, when I plug the FTDI Cable 5V, things get really noisy on the Nano TX pin, see screenshot below:

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

To be clear, that is what is going on on the Nano TX pin without me doing anything (right after connecting the cable to the Nano board), no commands are issued to the Nano board but the Nano board is essentially going nuts sending signals no one is asking for. Why would that be? If I then issue a command to the Nano via the 'Universal Reader Assistant' to detect the board I see the Nano RX line receiving the command but the Nano TX line continues to go nuts. The baud speeds are just fine, they are the same on both the CH340G and FTDI Cable 5V.

Regarding your CTS pin question, based on the [schematics](https://www.sparkfun.com/datasheets/DevTools/FTDI%20Cable%205V.pdf), the CTS pin appears to be pulled up, if you would like me to experiment by pulling the pin low I can do that but I would need to know exactly how to do that since I have very limited electronics knowledge and I don't want to burn something up. It may be also worth mentioning that the Nano board does not use the CTS pin (is not connected / NC) so I am not sure if the state of the pin matters or not.

Given that the FTDI Cable 5V cable works perfectly fine with an Arduino board, I still think that this is not an issue with the cable, I still believe this is an issue with the Nano serial circuitry being unstable under certain conditions (like long cables perhaps). I say this because trying to get the serial communication working with the Nano and a device such as a Raspberry Pi is very unstable.

Thanks.

nseidle, 2021-12-31:
CTS: the FTDI pulls it up, CH340x board leaves it floating. I'm not sure why the Nano is sending so much TX noise. Sorry, but because of the holidays I won't have access to hardware to replicate your issue until late next week.

ReneElizondo, 2022-01-15:
Nathan,

Not sure if you are still looking into this but in case you are. The screenshot below shows the oscilloscope signal coming directly from a Raspberry Pi TX pin (3V). Note that the pin is not connected to the Nano board, its just floating, but I also connected the pin to resistor and got the same result. Its a relatively nice clean signal.

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

The screenshot below shows the oscilloscope signal coming directly from the same Raspberry Pi TX pin (3V) but this time, the TX pin is connected to the Nano RX pin:

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

You can see all the noise introduced by the Nano. I get similar results if I use a level shifter. Why the noise? Does this not mean there is something up with the Nano design?

Thanks.

ReneElizondo, 2022-01-16:
Looks like even the Serial Basic Breakout - CH340G signal goes nuts when I plug in the oscilloscope. The Nano will stop working if all I do is plug the oscilloscope to the RX or TX pin. The moment I unplug the oscilloscope the Nano goes back to working. Not sure what is going on but looks like the Nano board has some issues.

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

nseidle, 2022-01-18:
I don't have answers, only head scratching.

* CH340E and CH340G connect to the M6E (you call it the Nano) great when direct to the port on my computer, but fail when used through a hub.
* The [FTDI 5V with 5V IO](https://www.sparkfun.com/products/9718) enumerates on my computer but cannot connect to the M6E. And fails even to enumerate through the hub.

Looking at serial signals, I am seeing similar noise at the TXO pin on the M6E board, sometimes. My current guess is that the M6E internal DC buck/boost is feeding noise back into the TXB0104 digital buffer causing it to spew bad serial. I detached the TXB0104 from the 3.3V coming from the M6E and fed it a separate 3.3V but that did not allow the FTDI to connect.

I'll check with our tech support team to see if they've seen or heard anything similar.

ReneElizondo, 2022-01-18:
These readers (from jadaktech) have issues enumerating through USB. In case it help, I created the following thread on the Pi forums some time ago:

https://forums.raspberrypi.com/viewtopic.php?t=320242
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
paulvha, 2022-01-20:
Thanks,

Can you share the exact RPI-pin to RFID-pin connections  (also VCC)
What program did you use to test?

regards,
Paul

ReneElizondo, 2022-01-22:
My apologies for the long delay, something urgent came up and I got side tracked.

To answer your question. From the RPI side I have the following setup:

*) 5 Volts from physical pin 4.
*) Ground from physical pin 6.
*) TX from physical pin 8.

From the M6E side:

*) 5 Volts to FTDI connector pin labeled VCC.
*) Ground to FTDI connector pin labeled GND.
*) TX (from RPI) to FTDI connector pin labeled RXI.

The program I used to test this is a custom .NET Core / C# app that basically attempts to open a connection to the M6E and read a tag. If you want it I can upload it but its pretty big since it needs to have all the .NET Core runtime. My guess is that any serial signal sent from any app will cause the same issue.

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

The output on the oscilloscope looks like this in my side:

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

Look forward from learning about your findings!

paulvha, 2022-01-22:
I connected to my RPI- 4 in the same way as you did. I have also connected the M6E-TX to either 5K6 OR pin 10 (UART0-RX).

Connected the logic analyzer to RX, TXm GND, and 5V. As I did not have the program, I used a simple Python program testserial.py:

```
#!/usr/bin/env python

import time
import serial

ser = serial.Serial(
    port='/dev/serial0',
    baudrate = 115200,
    parity=serial.PARITY_NONE,
    stopbits=serial.STOPBITS_ONE,
    bytesize=serial.EIGHTBITS,
    timeout=1
)

while 1:
    ser.write('\xff')
    ser.write('\x00')
    ser.write('\x03')
    ser.write('\x1d')
    ser.write('\x0C')

    time.sleep(1)
```
You can run this from a terminal with the command:  python testserial.py

It worked without a problem, (P.s. I have not connected the 3V3 so it shows zero) :
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

I have tried to remove the power and reconnect the 5V while the RPI was powered: NO difference.
I have tried to remove the RX-line and reconnect while the RPI was powered: NO difference.
I have tried to remove the TX-line and reconnect while the RPI was powered: NO difference.
I have tried to remove the RX-LINE  & TX-line and reconnect while the RPI was powered: NO difference.

Looked at the picture of your scope:
1. Is the scope probe set to 10X ( that will decrease the impact the scope probe has on the circuit)
2. connect the M6E TX  to the UART0 RX to create a resistor load
3. check the 5V with another scope probe at the same time. Some 5V wall suppliers deliver a too low current

regards,
Paul

ReneElizondo, 2022-01-22:
Thanks Paul,

You where absolutely correct regarding the prove setting, I had it at 1X and after I changed it to 10X the signal looked a lot better:

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

There is still some ringing in the signal but I assume that is just an oscilloscope artifact:

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

This is puzzling, I am still not sure why I can't get the M6E to work consistently reliably with the Pi. I will continue to explore and see if I can figure out what the problem is.

If you don't mind I have a quick question for you. In theory, if I feed a 5 volt signal to the M6E RX pin, the 5V signal would get translated to 3.3 V via the built in TXB0104 chip. The question is, what happens if instead of feeding a 5V signal to the M6E RX pin I feed a 3.3V signal? What would the TXB0104 chip do? Would it output 3.3V on the low voltage side because that is as low as its supposed to go? Or would it interpolate the value and output a much lower signal like say 1.5V?

Sorry for the dumb question, I can try this that myself (and I will) but I am curious as to what the expected result should be so I know what to look for (just so I can double check myself).

Thanks.

paulvha, 2022-01-23:
Good it works now much better.

The "ringing" is often the result of the capacitive impact of either or combination of the wires, the connections,  the scope, the logic (either Raspberry or M6E).

As it relates to your TXB0104 question, it **translates** the M6E-RX line level on the VVC-A side to the output level of VCC-B. It detects a "1" compared to the VCC-A level and then outputs a "1" based on VCC-B level. (VVC-A = 5V, VCC-B = 3V3)  It is NOT stepping down the input signal.

For the M6E-TX it does the opposite translation. The M6E-TX output will be to the level of VCC-A. As you see on my post that shows ~4.2V. This can be TOO high for the Raspberry (max should be 3V3) causing misreadings and/or damage. So include a resistor based level shifter on the M6E-TX line ONLY :

```
GND ------| 10K  |-----!---- | 5k6 |------  TX from Nano
                       !
                       !
                  Pin 8 ( UAR0-RX)
```
Normally I use the M6E on Raspberry Pi with the USB connection.

Regards,
Paul

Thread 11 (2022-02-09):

Expose 3V RX/TX Pins.

ReneElizondo, 2022-02-09:
As it stands, in order to communicate with the **_SparkFun Simultaneous RFID Reader - M6E Nano_**,  via the RX/TX pins (the only way to communicate with that board) you must use 5V logic. This is nice if you are using the standard Arduino board to do that, but a lot of other products (if not most) use 3V logic making communicating with the RFID board unnecessarily complex (having to use voltage shifters / resistors to lower the voltage etc).

Given that the M6E uses 3V on the RX/TX pins by design, it would be nice if those pins where exposed directly to the outside world (via pin headers). This would make it very easy for devices such as the Raspberry Pi (and many others) to **_easily_** and **_directly_** communicate with the RFID board using the RX/TX pins without needing anything in between.

Please keep in mind that the Mercury API (the code that is used to communicated with the M6E) is supported in most operating system, also, keep in mind that the Mercury API is supported in Java, .NET Core, etc. This basically means that creating apps that run in Raspberry Pi boards that communicate with the M6E very, very, easy. In other words, the Arduino board is not the only game in town when it comes to communicating with the M6E. As a matter of fact (this is my personal opinion) creating apps for the M6E in Linux / Raspberry Pi boards is much more attractive than the Arduino board with all its limitations, just my thoughts.

Thanks.

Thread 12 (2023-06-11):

try to read data from RFM3250

fawadbutt, 2023-06-11:
hi i am try to read temperature value from RFM3250 Rugged Temperature Sensor. for this i am using M6E nano RFID tag reader.  with sparkfun lib i run example its run , but not able to read temperature value.  someone give example ,, i am using esp32. thanks

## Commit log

2016-10-05 Many changes from design review
    [UHF_RFID_Nano_Shield.brd, UHF_RFID_Nano_Shield.sch]
2016-10-06 Fixed problems found during review
    [Simultaneous_RFID_Tag_Reader.brd, Simultaneous_RFID_Tag_Reader.sch, UHF_RFID_Nano_Shield.brd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]
2016-10-10 Fixed airwire
    [Simultaneous_RFID_Tag_Reader.brd]
2016-10-25 Finalizing antenna. Adding buzzer.
2016-11-01 Added heat sink area and mounting holes.
    [Simultaneous_RFID_Tag_Reader.brd, Simultaneous_RFID_Tag_Reader.sch]
2016-11-01 Adding buzzer labels
    [Simultaneous_RFID_Tag_Reader.brd, Simultaneous_RFID_Tag_Reader.sch]
2016-11-07 Changing input silk to 3.7-5V.
    [Simultaneous_RFID_Tag_Reader.brd, Simultaneous_RFID_Tag_Reader.sch]
2016-11-22 Finishing matching network to u.FL
    [Simultaneous_RFID_Tag_Reader.brd, Simultaneous_RFID_Tag_Reader.sch]
2016-12-15 Adding cosmetic GND connection to schematic.
    [Simultaneous_RFID_Tag_Reader.brd, Simultaneous_RFID_Tag_Reader.sch]
2017-01-18 Adding dims to board. Updating readme.
    [Simultaneous_RFID_Tag_Reader.brd]
2017-01-18 Squashed 'Libraries/Arduino/' content from commit 09f6561
    git-subtree-dir: Libraries/Arduino
    git-subtree-split: 09f65617289656be7bcbb42c2a57301124a67a72
2017-02-24 Squashed 'Libraries/Arduino/' changes from 09f6561..d445e0f
    d445e0f Incrementing library version
    3fe6b17 Fixed bug: don't call printArray unless debug port has been defined.
    ef7f551 Renaming of example fines
    d9fd735 Renaming of example files
    git-subtree-split: d445e0fc11d1f5940b91b91c6c6669cd72d339cb
    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

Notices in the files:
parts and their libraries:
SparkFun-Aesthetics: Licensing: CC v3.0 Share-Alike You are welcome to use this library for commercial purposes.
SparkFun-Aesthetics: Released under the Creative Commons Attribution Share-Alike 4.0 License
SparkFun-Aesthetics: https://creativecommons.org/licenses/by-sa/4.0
